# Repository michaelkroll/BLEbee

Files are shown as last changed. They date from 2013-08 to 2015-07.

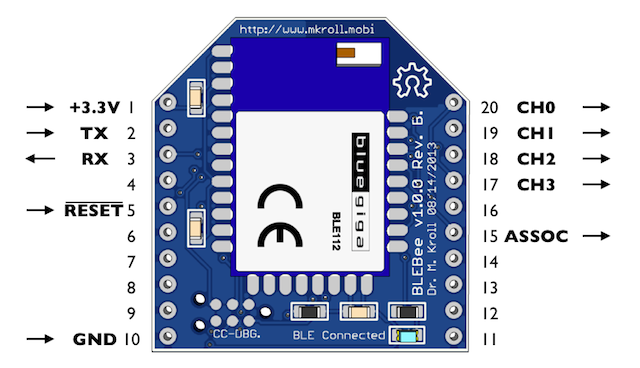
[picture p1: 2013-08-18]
docs/BLEBee-v1.0.0-Rev.B.-Pin-Out.png

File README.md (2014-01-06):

### BLEbee

The MIT License (MIT)
Copyright (c) 2012-2014 Dr. Michael Kroll
 
Permission is hereby granted, free of charge, to any person obtaining a copy of this software and associated 
documentation files (the "Software"), to deal in the Software without restriction, including without limitation 
the rights to use, copy, modify, merge, publish, distribute, sublicense, and/or sell copies of the Software, 
and to permit persons to whom the Software is furnished to do so, subject to the following conditions:
 
The above copyright notice and this permission notice shall be included in all copies or substantial portions of the Software.
 
THE SOFTWARE IS PROVIDED "AS IS", WITHOUT WARRANTY OF ANY KIND, EXPRESS OR IMPLIED, INCLUDING BUT NOT 
LIMITED TO THE WARRANTIES OF MERCHANTABILITY, FITNESS FOR A PARTICULAR PURPOSE AND NONINFRINGEMENT. IN 
NO EVENT SHALL THE AUTHORS OR COPYRIGHT HOLDERS BE LIABLE FOR ANY CLAIM, DAMAGES OR OTHER LIABILITY, 
WHETHER IN AN ACTION OF CONTRACT, TORT OR OTHERWISE, ARISING FROM, OUT OF OR IN CONNECTION WITH THE 
SOFTWARE OR THE USE OR OTHER DEALINGS IN THE SOFTWARE.

### Content

The final design of the BLEBee v1.0.0 Rev.B. looks as on the illustration below. Please use the pinout as illustrated. 

(https://raw.github.com/michaelkroll/BLEbee/master/docs/BLEBee-v1.0.0-Rev.B.-Pin-Out.png)

http://www.mkroll.mobi

http://forum.mkroll.mobi

This repository contains the eagle design files as well as the firmware source code which are needed modify and rebuild the firmware. The hexfiles are included as well. Moreover I added the Arduino Sketches from my blog to this repository as well.

Notes for BLEbee 1.0.0:
-----

-The Eagle design files are created using Eagle v6.4.0

-The Firmware v1.0.0 for the BLE112 module on the BLEbee was created and compiled for the Bluegiga BLE112 SDK v1.1.1-b71

-The Firmware v1.0.1 for the BLE112 module on the BLEbee was created and compiled for the Bluegiga BLE112 SDK v1.2.1-b91

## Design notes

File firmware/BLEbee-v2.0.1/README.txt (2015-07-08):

Firmware v2.0.1 is a backport of the v1.0.1 firmware for the BLEBee v2.0.0

The UART i sconfigured to be available as follows:

TX P0_4
RX P0_5

Additional ouput pins are connected as follows: 

Connected LED 		P1_0
Assoc / BLE Connected 	P1_1

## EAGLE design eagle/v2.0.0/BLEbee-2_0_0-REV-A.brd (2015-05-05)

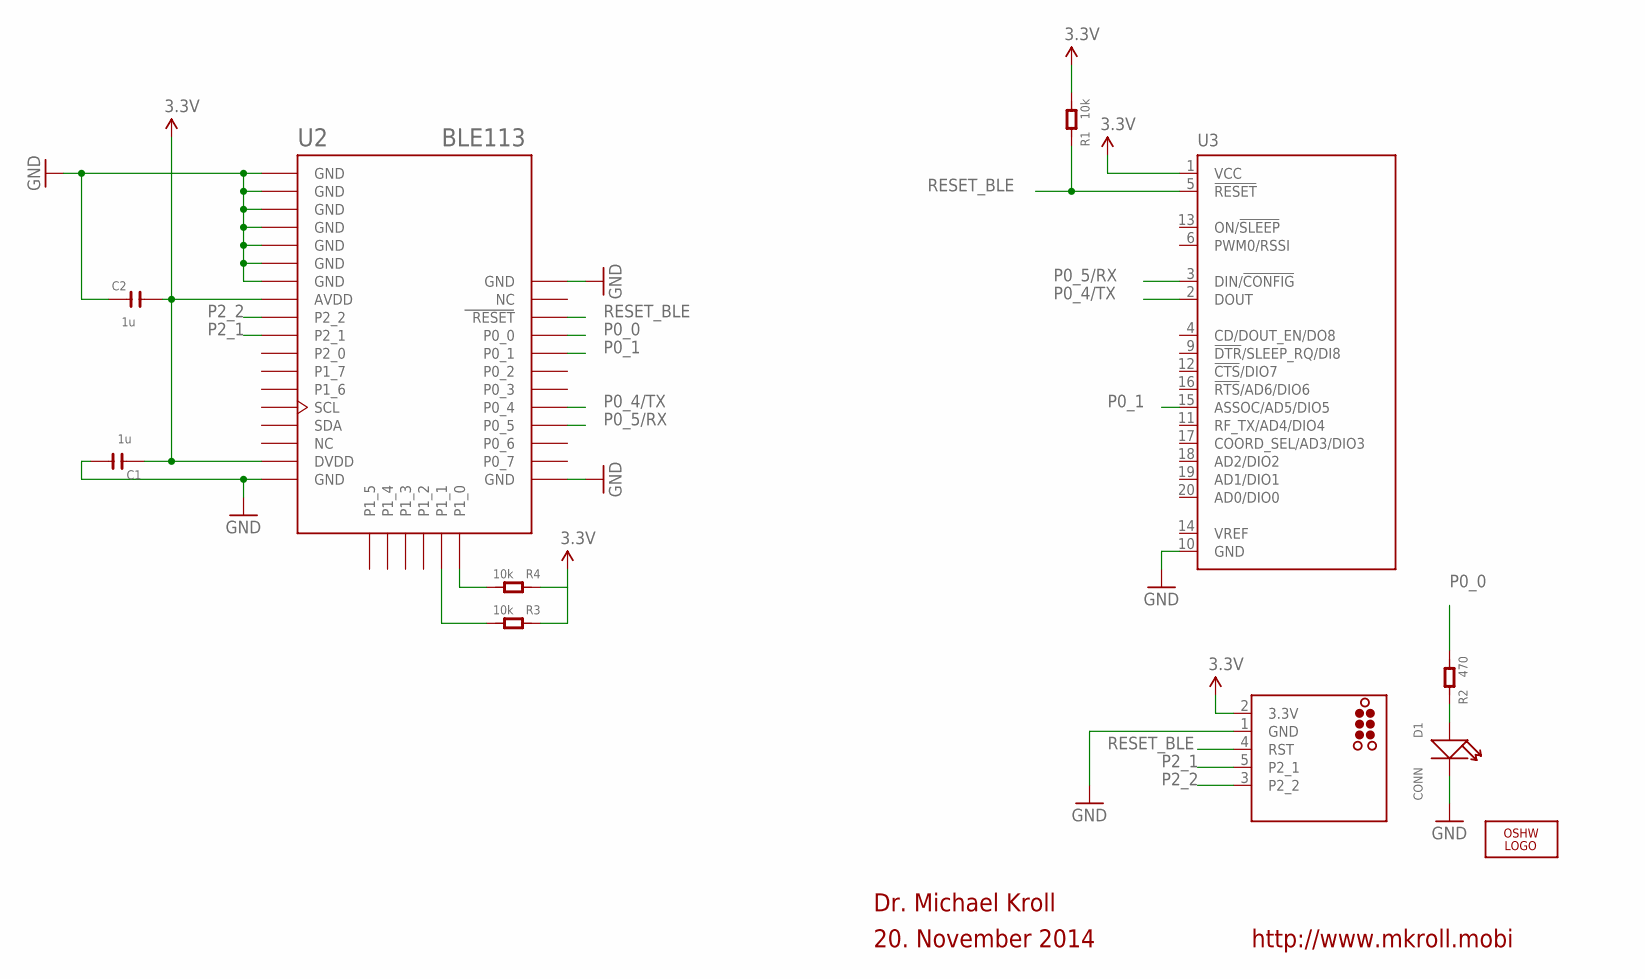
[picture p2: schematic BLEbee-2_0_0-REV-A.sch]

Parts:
C1, C2: 1u; C0603
D1: CONN; LED0603
J1: TC2030-CC-DEBUGGER; TC2030-MCP-NL
LOGO1: LOGO-OSHW-6MILX0100-NT; OSHW_6X100_NOTEXT
R1, R3, R4: 10k; R0603
R2: 470; R0603
U2: BLE113; BLE113-A
U3: MODULE_BEE-XBEE-DIP; MODULE_20P-DIP-2.0-W/-SILK

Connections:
3.3V: C1.2, C2.1, J1.2 (3.3V), R1.2, R3.1, R4.1, U2.AVDD, U2.DVDD, U3.1 (VCC)
GND: C1.1, C2.2, D1.-, J1.1 (GND), U2.GND, U2.GND@2 (GND), U2.GND@3 (GND), U2.GND@4 (GND), U2.GND@5 (GND), U2.GND@6 (GND), U2.GND@7 (GND), U2.GND@8 (GND), U2.GND@9 (GND), U2.GND@10 (GND), U3.10 (GND)
unnamed: D1.+, R2.1
unnamed: R4.2, U2.P1_0
unnamed: R3.2, U2.P1_1
P0_0: R2.2, U2.P0_0
P0_1: U2.P0_1, U3.15 (ASSOC/AD5/DIO5)
P0_4/TX: U2.P0_4, U3.2 (DOUT)
P0_5/RX: U2.P0_5, U3.3 (DIN/!CONFIG)
P2_1: J1.5 (P2_1), U2.P2_1
P2_2: J1.3 (P2_2), U2.P2_2
RESET_BLE: J1.4 (RST), R1.1, U2.RESET, U3.5 (!RESET)

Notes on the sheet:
Dr. Michael Kroll
20. November 2014
http://www.mkroll.mobi

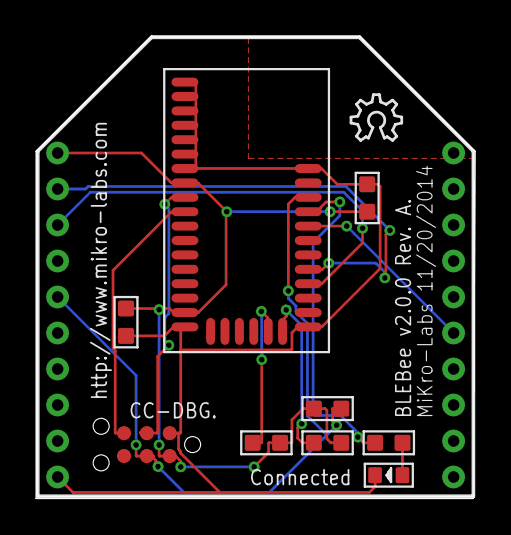
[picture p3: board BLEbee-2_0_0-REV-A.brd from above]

Board: 4 copper layers, 24.4 x 25.7 mm, 12 parts (1 on the bottom side), 12 nets.

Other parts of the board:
U$1: MIKROLABS-LOGO

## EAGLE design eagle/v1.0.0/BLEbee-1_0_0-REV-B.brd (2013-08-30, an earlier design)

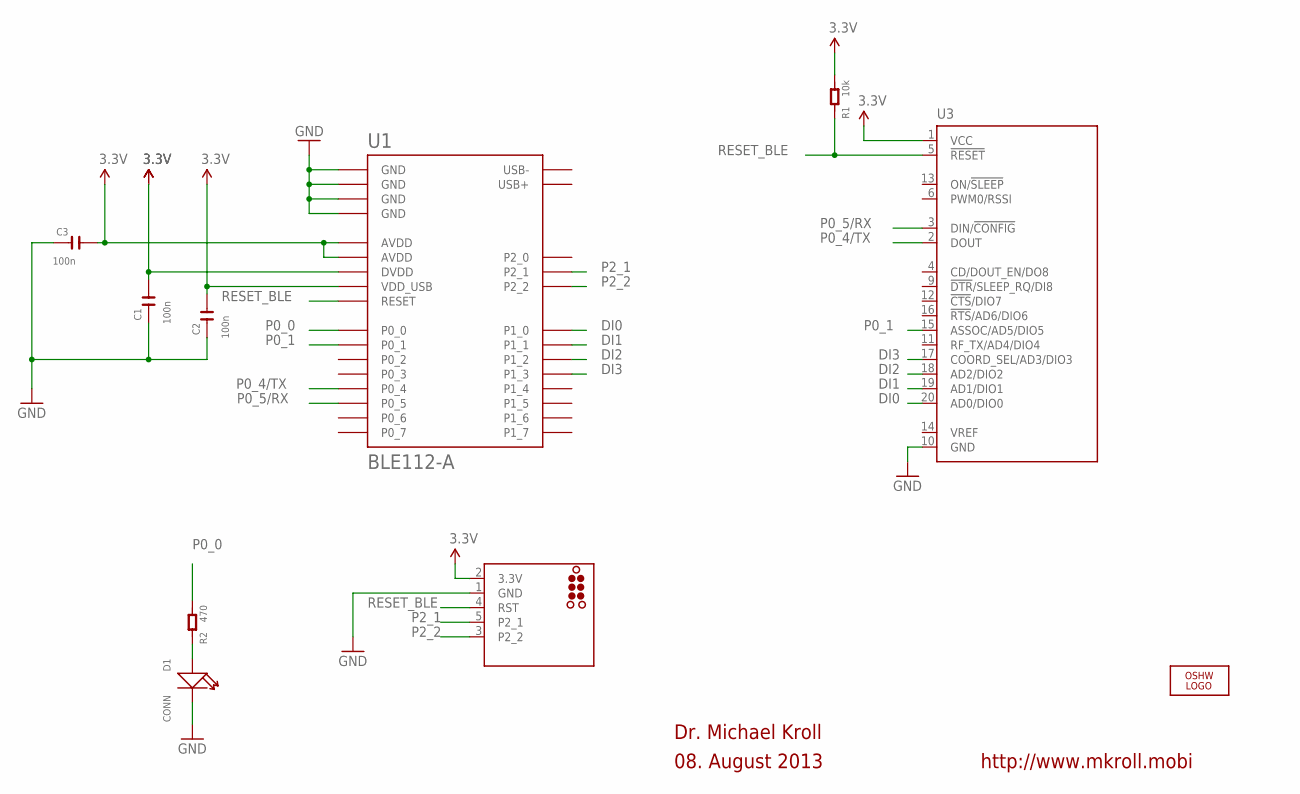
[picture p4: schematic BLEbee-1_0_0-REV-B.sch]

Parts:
C1, C2, C3: 100n; C0603
D1: CONN; LED0603
J1: TC2030-CC-DEBUGGER; TC2030-MCP-NL
LOGO1: LOGO-OSHW-6MILX0100-NT; OSHW_6X100_NOTEXT
R1: 10k; R0603
R2: 470; R0603
U1: BLE112-A
U3: MODULE_BEE-XBEE-DIP; MODULE_20P-DIP-2.0-W/-SILK

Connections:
3.3V: C1.1, C2.1, C3.1, J1.2 (3.3V), R1.2, U1.AVDD1 (AVDD), U1.AVDD2 (AVDD), U1.DVDD, U1.VDD_USB, U3.1 (VCC)
DI0: U1.P1_0, U3.20 (AD0/DIO0)
DI1: U1.P1_1, U3.19 (AD1/DIO1)
DI2: U1.P1_2, U3.18 (AD2/DIO2)
DI3: U1.P1_3, U3.17 (COORD_SEL/AD3/DIO3)
GND: C1.2, C2.2, C3.2, D1.-, J1.1 (GND), U1.GND1 (GND), U1.GND2 (GND), U1.GND3 (GND), U1.GND4 (GND), U3.10 (GND)
unnamed: D1.+, R2.1
P0_0: R2.2, U1.P0_0
P0_1: U1.P0_1, U3.15 (ASSOC/AD5/DIO5)
P0_4/TX: U1.P0_4, U3.2 (DOUT)
P0_5/RX: U1.P0_5, U3.3 (DIN/!CONFIG)
P2_1: J1.5 (P2_1), U1.P2_1
P2_2: J1.3 (P2_2), U1.P2_2
RESET_BLE: J1.4 (RST), R1.1, U1.RESET, U3.5 (!RESET)

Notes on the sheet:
Dr. Michael Kroll
08. August 2013
http://www.mkroll.mobi

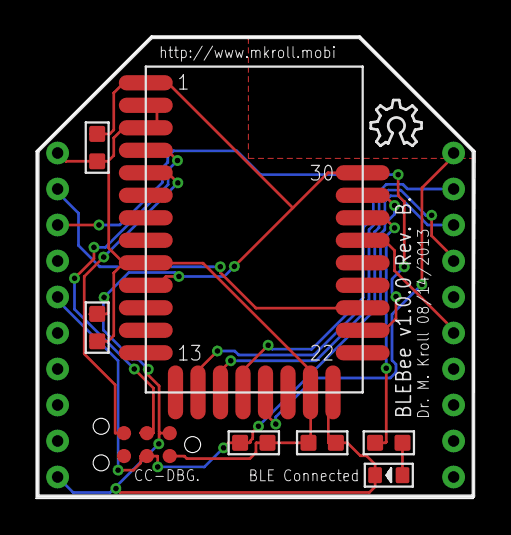
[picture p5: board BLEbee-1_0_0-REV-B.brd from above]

Board: 4 copper layers, 24.4 x 25.7 mm, 10 parts (0 on the bottom side), 14 nets.

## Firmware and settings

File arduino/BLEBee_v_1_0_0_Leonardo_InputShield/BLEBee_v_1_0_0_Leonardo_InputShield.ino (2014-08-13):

/*
 * BLEbee Test Sketch for Arduino 1.0.5
 * v1.0.0 2013-08-30
 * 
 * This Sketch was created to use the BLEBee as the communication gateway to build a
 * BLE joystick using DFRobots Input Shield V2 http://www.dfrobot.com/index.php?route=product/product&path=35_124&product_id=62
 * and an Arduino Leonardo
 *
 * Copyright (c) 2014 Dr. Michael Kroll
 *
 * http://www.mkroll.mobi
 * http://forum.mkroll.mobi
 *
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
 * THE SOFTWARE IS PROVIDED "AS IS", WITHOUT WARRANTY OF ANY KIND, EXPRESS OR IMPLIED, 
 * INCLUDING BUT NOT LIMITED TO THE WARRANTIES OF MERCHANTABILITY, FITNESS FOR A PARTICULAR 
 * PURPOSE AND NONINFRINGEMENT. IN NO EVENT SHALL THE AUTHORS OR COPYRIGHT HOLDERS BE LIABLE 
 * FOR ANY CLAIM, DAMAGES OR OTHER LIABILITY, WHETHER IN AN ACTION OF CONTRACT, TORT OR OTHERWISE, 
 * ARISING FROM, OUT OF OR IN CONNECTION WITH THE SOFTWARE OR THE USE OR OTHER DEALINGS IN THE SOFTWARE.
 */

#define up_button	8
#define down_button	A1
#define left_button	9
#define right_button	12
#define stick_button	A0
#define joystick_x	A2
#define joystick_y	A3

int old_left_state = 0;
int old_right_state = 01;
int old_up_state = 0;
int old_down_state = 0;
int old_stick_state = 0;
int old_joystick_x_value = 524;
int old_joystick_y_value = 517;

int counter = 0;

void setup()   {
  // Set the baudrate of the Arduino
  Serial.begin(9600);
  Serial.print("BLEbee v1.0.0 Sketch setup...");

  pinMode (left_button,  INPUT);
  pinMode (right_button, INPUT);
  pinMode (up_button,    INPUT);
  pinMode (down_button,  INPUT);

  pinMode (stick_button, INPUT);
  pinMode (joystick_x,   INPUT);
  pinMode (joystick_y,   INPUT);

  // Set the data rate for the Serial1 where the BLEbee is connected to
  // The BLEBee's baudrate can be controlled by characteristic: 
  // 2FBC0F31-726A-4014-B9FE-C8BE0652E982
  // 0x00 = 9600 (default)
  // 0x01 = 14400
  // 0x02 = 19200
  // 0x03 = 28800
  // 0x04 = 38400
  Serial1.begin(9600);
  Serial.println(" done.");
}

void loop() // run over and over
{
  int left_state = digitalRead (left_button);
  int right_state = digitalRead (right_button);
  int up_state = digitalRead (up_button);
  int down_state = digitalRead (down_button);
  int stick_state = digitalRead (stick_button);

  int joystick_x_value = analogRead (joystick_x);
  int joystick_y_value = analogRead (joystick_y);

  // check if states have changed
  if (old_left_state != left_state) {
    old_left_state = left_state;
    if (left_state == 0) {
      Serial1.print(counter++);
      Serial1.print(" - ");
      Serial1.println("LEFT_PRESSED");
    }
    else {
      Serial1.print(counter++);
      Serial1.print(" - ");
      Serial1.println("LEFT_RELEASED");    
    }
  }
  
  if (old_right_state != right_state) {
    old_right_state = right_state;
    if (right_state == 0) {
      Serial1.print(counter++);
      Serial1.print(" - ");
      Serial1.println("RIGHT_PRESSED");
    }
    else {
      Serial1.print(counter++);
      Serial1.print(" - ");
      Serial1.println("RIGHT_RELEASED");    
    }
  }
  
  if (old_up_state != up_state) {
    old_up_state = up_state;
    if (up_state == 0) {
      Serial1.print(counter++);
      Serial1.print(" - ");
      Serial1.println("UP_PRESSED");
    }
    else {
      Serial1.print(counter++);
      Serial1.print(" - ");
      Serial1.println("UP_RELEASED");    
    }  
  }
  
  if (old_down_state != down_state) {
    old_down_state = down_state;
    if (down_state == 0) {
      Serial1.print(counter++);
      Serial1.print(" - ");
      Serial1.println("DOWN_PRESSED");
    }
    else {
      Serial1.print(counter++);
      Serial1.print(" - ");
      Serial1.println("DOWN_RELEASED");    
    }  
  }
  
  if (old_stick_state != stick_state) {
    old_stick_state = stick_state;
    if (stick_state == 0) {
      Serial1.print(counter++);
      Serial1.print(" - ");
      Serial1.println("STICk_PRESSED");
    }
    else {
      Serial1.print(counter++);
      Serial1.print(" - ");
      Serial1.println("STICK_RELEASED");    
    }  
  }

  int treshhold_x = abs(old_joystick_x_value - joystick_x_value);  
  if (treshhold_x > 3) {
    old_joystick_x_value = joystick_x_value;
    Serial.print(counter++);
    Serial.print(" - ");
    Serial.print("JOYSTICK_X=");  
    Serial.println(joystick_x_value);    
  }
  
  int treshhold_y = abs(old_joystick_y_value - joystick_y_value);
  if (treshhold_y > 3) {
    old_joystick_y_value = joystick_y_value;
    Serial.print(counter++);
    Serial.print(" - ");
    Serial.print("JOYSTICK_Y=");  
    Serial.println(joystick_y_value);    
  }

  // Wait for Data on the serial console and submit it to the
  // BLEBee byte per byte. there is no longer a buffer involved.
  if (Serial.available()) {
    int ch = Serial.read();
    Serial.print(ch);
    Serial1.write(ch);
  }

  // Wait for data send from the iPhone and print it to the serial console.
  // That's it. Quite simple.
  if (Serial1.available()) {
    Serial.write(Serial1.read());
  }
  delay(50);
}

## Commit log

2012-11-04 initial version commited to github.
    [BLEbee-0_7_1.brd, BLEbee-0_7_1.sch]
2013-06-30 Design files, firmware files and Arduino FIO v3 Arduino Sketch added.
    [BLEbee-1_0_0.brd, BLEbee-1_0_0.sch]
2013-07-03 Demo Sketch for the Arduino FIO added.
2013-08-18 pin out added to the README.me file.
2013-08-22 wrong pin descriptions for the connect led and the assoc pin fixed.
2013-08-30 BLEBee v1.0.0 Revision B schematic and board file added.
    [BLEbee-1_0_0-REV-B.brd, BLEbee-1_0_0-REV-B.sch]
2013-08-30 Arduino FIO v3 Sample Sketch added.
2013-08-30 Arduino Leonardo with Wirless Proto Shield sample added.
2013-09-01 Test Sketch for the Arduino FIO.
2013-09-22 Old prototype files removed.
    [BLEbee-0_7_1.brd, BLEbee-0_7_1.sch, BLEbee-1_0_0.brd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]
2014-07-26 new input shield sample added.
2014-12-07 Version 2.0.0 of the firmware prepared for the new hardware revision v2.0.0 using the BLE113.
    [BLEbee-1_0_0-REV-B.brd, BLEbee-1_0_0-REV-B.sch]
2015-05-05 Eagle design files for the new BLEBee v2.0.0 added.
    [BLEbee-2_0_0-REV-A.brd, BLEbee-2_0_0-REV-A.sch]
2015-07-07 New Arduino Sketch Added to run the BLEBee v2.0.0 using the Wireless Proto Shield on an Arduino Leonardo.

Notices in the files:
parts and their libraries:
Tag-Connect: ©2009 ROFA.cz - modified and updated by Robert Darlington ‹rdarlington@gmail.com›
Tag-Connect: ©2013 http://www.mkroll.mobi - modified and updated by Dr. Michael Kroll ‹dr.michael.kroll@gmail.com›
